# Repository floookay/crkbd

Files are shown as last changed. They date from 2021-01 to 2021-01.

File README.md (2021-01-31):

# Corne keyboard fork

The Corne keyboard is a split keyboard with 3x6 column staggered keys and 3 thumb keys,
based on [Helix](https://github.com/MakotoKurauchi/helix).
Crkbd stands for Corne Keyboard.

## Corne MX Low Profile

This fork altered the footprints of the Corne Classic to support Cherry MX Low Profile switches.  
For more information on how to build one see [here](./corne-mxlp/doc/buildguide_en.md)




### Compability

Despite the MX style stem of the switches these are not compatible with every MX style keycap. I included some more information in the build guide.

### RGB

The switches route the light of the RGB LEDs quite nicely imo: <https://imgur.com/7JVrjXo>



### PCB

I designed the footprint for the MXLP switch based on my measurements. The footprint file is included with the PCB. The switch has a tight fit.



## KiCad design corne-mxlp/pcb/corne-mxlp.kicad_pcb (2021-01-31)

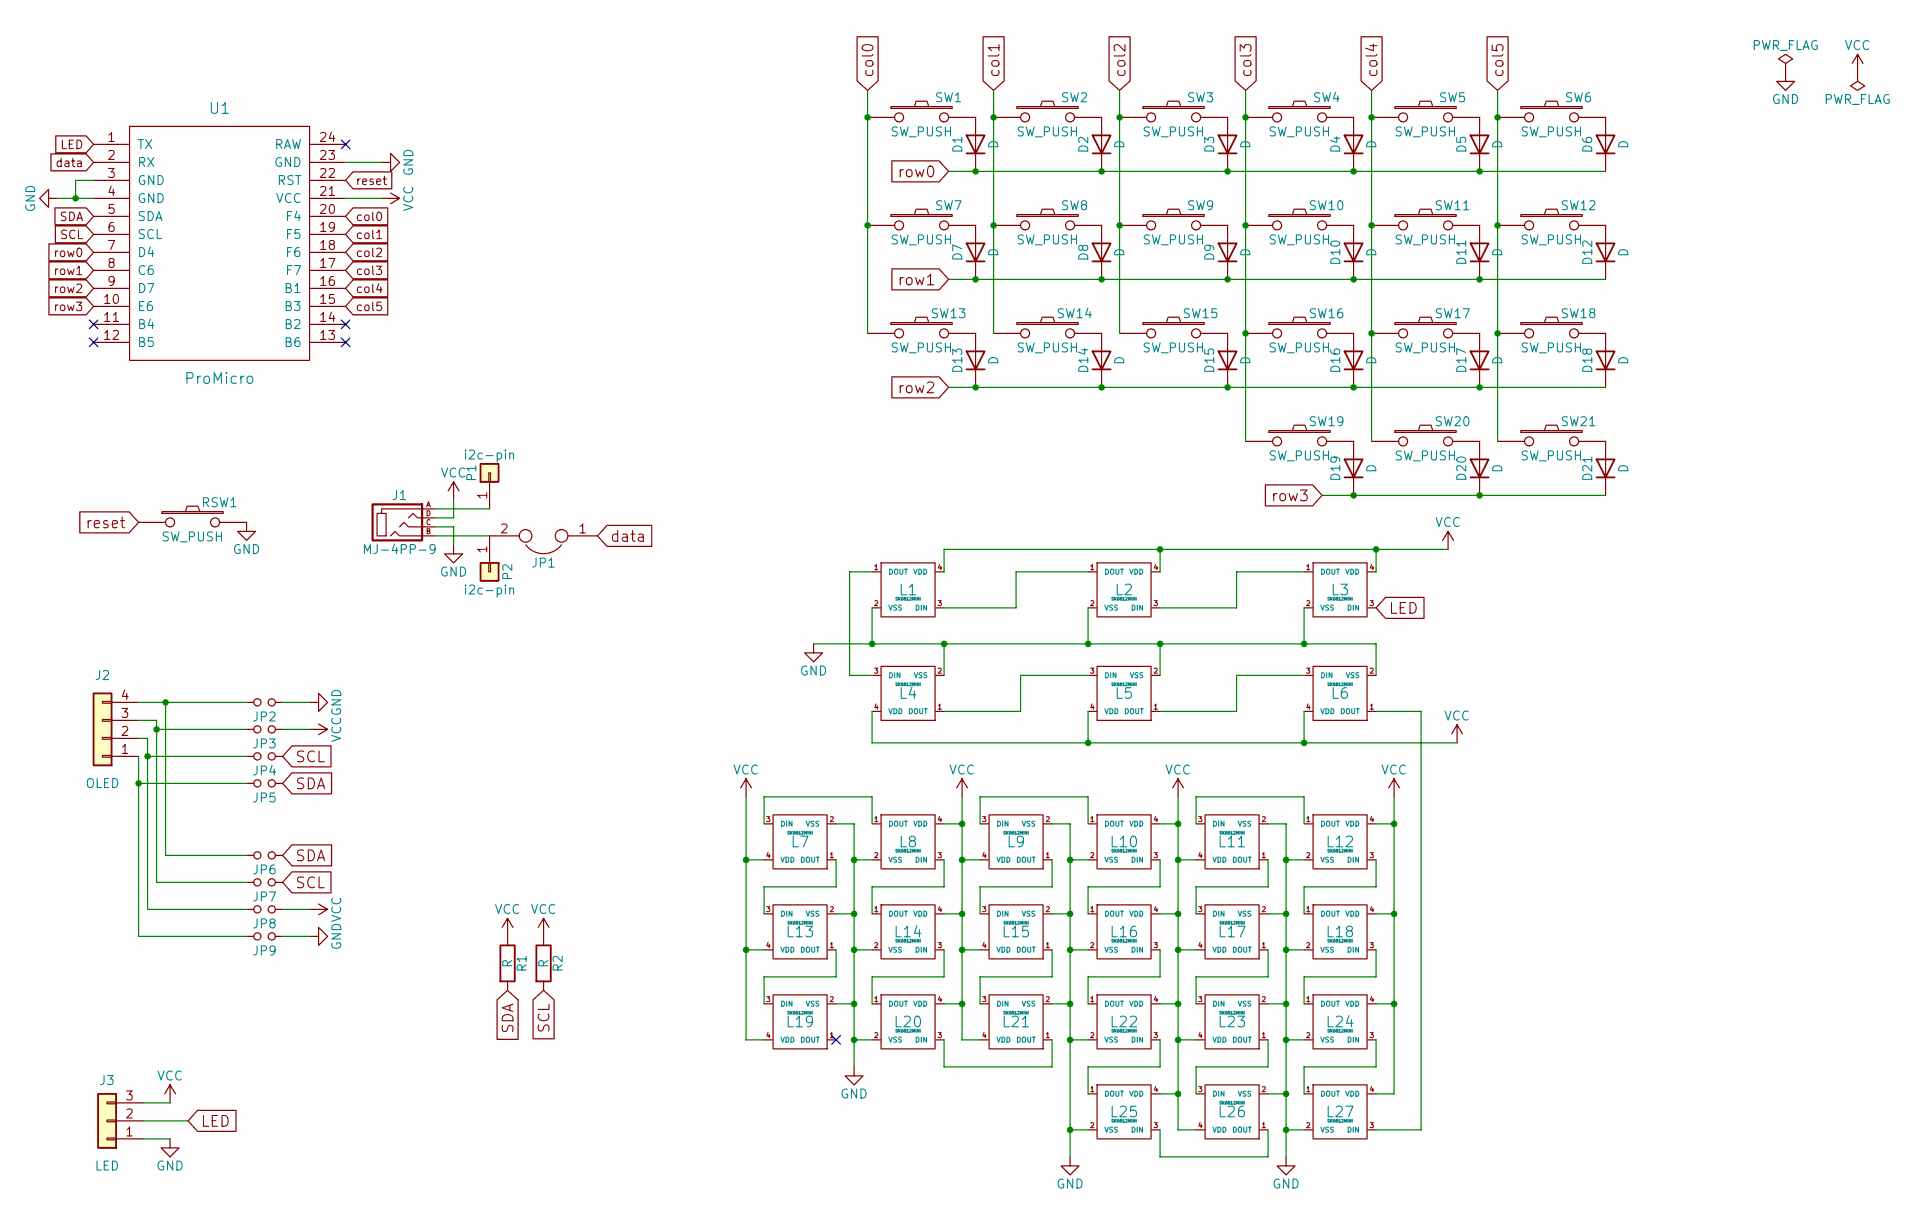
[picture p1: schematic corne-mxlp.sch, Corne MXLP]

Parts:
D1, D2, D3, D4, D5, D6, D7, D8, D9, D10, D11, D12, D13, D14, D15, D16, D17, D18, D19, D20, D21: D; D3_TH_SMD
J1: MJ-4PP-9
J2: OLED
J3: LED; StripLED_rev
JP1: JP
JP2, JP3, JP4, JP5, JP6, JP7, JP8, JP9: Jumper
L1, L2, L3, L4, L5, L6: SK6812MINI; SK6812MINI_underglow_rev
L7, L8, L9, L10, L11, L12, L13, L14, L15, L16, L17, L18, L19, L20, L21, L22, L23, L24, L25, L26, L27: SK6812MINI; SK6812MINI_rev
P1, P2: i2c-pin; 1pin_conn
R1, R2: R
RSW1: SW_PUSH; ResetSW
SW1, SW2, SW3, SW4, SW5, SW6, SW7, SW8, SW9, SW10, SW11, SW12, SW13, SW14, SW15, SW16, SW17, SW18, SW19, SW20, SW21: SW_PUSH; MXLP
U1: ProMicro; ProMicro_v2

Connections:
GND: J1.C, J3.1, JP2.1, JP9.1, L1.2 (VSS), L2.2 (VSS), L3.2 (VSS), L4.2 (VSS), L5.2 (VSS), L6.2 (VSS), L7.2 (VSS), L8.2 (VSS), L9.2 (VSS), L10.2 (VSS), L11.2 (VSS), L12.2 (VSS), L13.2 (VSS), L14.2 (VSS), L15.2 (VSS), L16.2 (VSS), L17.2 (VSS), L18.2 (VSS), L19.2 (VSS), L20.2 (VSS), L21.2 (VSS), L22.2 (VSS), L23.2 (VSS), L24.2 (VSS), L25.2 (VSS), L26.2 (VSS), L27.2 (VSS), RSW1.2, U1.3 (GND), U1.4 (GND), U1.23 (GND)
LED: J3.2, L3.3 (DIN), U1.1 (TX)
unnamed: D1.2 (A), SW1.2
unnamed: D2.2 (A), SW2.2
unnamed: D3.2 (A), SW3.2
unnamed: D4.2 (A), SW4.2
unnamed: D5.2 (A), SW5.2
unnamed: D6.2 (A), SW6.2
unnamed: D7.2 (A), SW7.2
unnamed: D8.2 (A), SW8.2
unnamed: D9.2 (A), SW9.2
unnamed: D10.2 (A), SW10.2
unnamed: D11.2 (A), SW11.2
unnamed: D12.2 (A), SW12.2
unnamed: D13.2 (A), SW13.2
unnamed: D14.2 (A), SW14.2
unnamed: D15.2 (A), SW15.2
unnamed: D16.2 (A), SW16.2
unnamed: D17.2 (A), SW17.2
unnamed: D18.2 (A), SW18.2
unnamed: D19.2 (A), SW19.2
unnamed: D20.2 (A), SW20.2
unnamed: D21.2 (A), SW21.2
unnamed: J1.A, P1.1
unnamed: J1.B, JP1.2, P2.1
unnamed: J2.1, JP5.2, JP9.2
unnamed: J2.2, JP4.2, JP8.2
unnamed: J2.3, JP3.2, JP7.2
unnamed: J2.4, JP2.2, JP6.2
unnamed: L1.1 (DOUT), L4.3 (DIN)
unnamed: L1.3 (DIN), L2.1 (DOUT)
unnamed: L2.3 (DIN), L3.1 (DOUT)
unnamed: L4.1 (DOUT), L5.3 (DIN)
unnamed: L5.1 (DOUT), L6.3 (DIN)
unnamed: L7.3 (DIN), L8.1 (DOUT)
unnamed: L9.3 (DIN), L10.1 (DOUT)
unnamed: L10.3 (DIN), L16.1 (DOUT)
unnamed: L11.1 (DOUT), L17.3 (DIN)
unnamed: L11.3 (DIN), L12.1 (DOUT)
unnamed: L12.3 (DIN), L18.1 (DOUT)
unnamed: L13.1 (DOUT), L19.3 (DIN)
unnamed: L7.1 (DOUT), L13.3 (DIN)
unnamed: L8.3 (DIN), L14.1 (DOUT)
unnamed: L14.3 (DIN), L20.1 (DOUT)
unnamed: L15.1 (DOUT), L21.3 (DIN)
unnamed: L9.1 (DOUT), L15.3 (DIN)
unnamed: L16.3 (DIN), L22.1 (DOUT)
unnamed: L17.1 (DOUT), L23.3 (DIN)
unnamed: L18.3 (DIN), L24.1 (DOUT)
unnamed: L20.3 (DIN), L21.1 (DOUT)
unnamed: L22.3 (DIN), L25.1 (DOUT)
unnamed: L23.1 (DOUT), L26.3 (DIN)
unnamed: L24.3 (DIN), L27.1 (DOUT)
unnamed: L25.3 (DIN), L26.1 (DOUT)
unnamed: L6.1 (DOUT), L27.3 (DIN)
SCL: JP4.1, JP7.1, R2.2, U1.6 (SCL)
SDA: JP5.1, JP6.1, R1.2, U1.5 (SDA)
VCC: J1.D, J3.3, JP3.1, JP8.1, L1.4 (VDD), L2.4 (VDD), L3.4 (VDD), L4.4 (VDD), L5.4 (VDD), L6.4 (VDD), L7.4 (VDD), L8.4 (VDD), L9.4 (VDD), L10.4 (VDD), L11.4 (VDD), L12.4 (VDD), L13.4 (VDD), L14.4 (VDD), L15.4 (VDD), L16.4 (VDD), L17.4 (VDD), L18.4 (VDD), L19.4 (VDD), L20.4 (VDD), L21.4 (VDD), L22.4 (VDD), L23.4 (VDD), L24.4 (VDD), L25.4 (VDD), L26.4 (VDD), L27.4 (VDD), R1.1, R2.1, U1.21 (VCC)
col0: SW1.1, SW7.1, SW13.1, U1.20 (F4)
col1: SW2.1, SW8.1, SW14.1, U1.19 (F5)
col2: SW3.1, SW9.1, SW15.1, U1.18 (F6)
col3: SW4.1, SW10.1, SW16.1, SW19.1, U1.17 (F7)
col4: SW5.1, SW11.1, SW17.1, SW20.1, U1.16 (B1)
col5: SW6.1, SW12.1, SW18.1, SW21.1, U1.15 (B3)
data: JP1.1, U1.2 (RX)
reset: RSW1.1, U1.22 (RST)
row0: D1.1 (K), D2.1 (K), D3.1 (K), D4.1 (K), D5.1 (K), D6.1 (K), U1.7 (D4)
row1: D7.1 (K), D8.1 (K), D9.1 (K), D10.1 (K), D11.1 (K), D12.1 (K), U1.8 (C6)
row2: D13.1 (K), D14.1 (K), D15.1 (K), D16.1 (K), D17.1 (K), D18.1 (K), U1.9 (D7)
row3: D19.1 (K), D20.1 (K), D21.1 (K), U1.10 (E6)

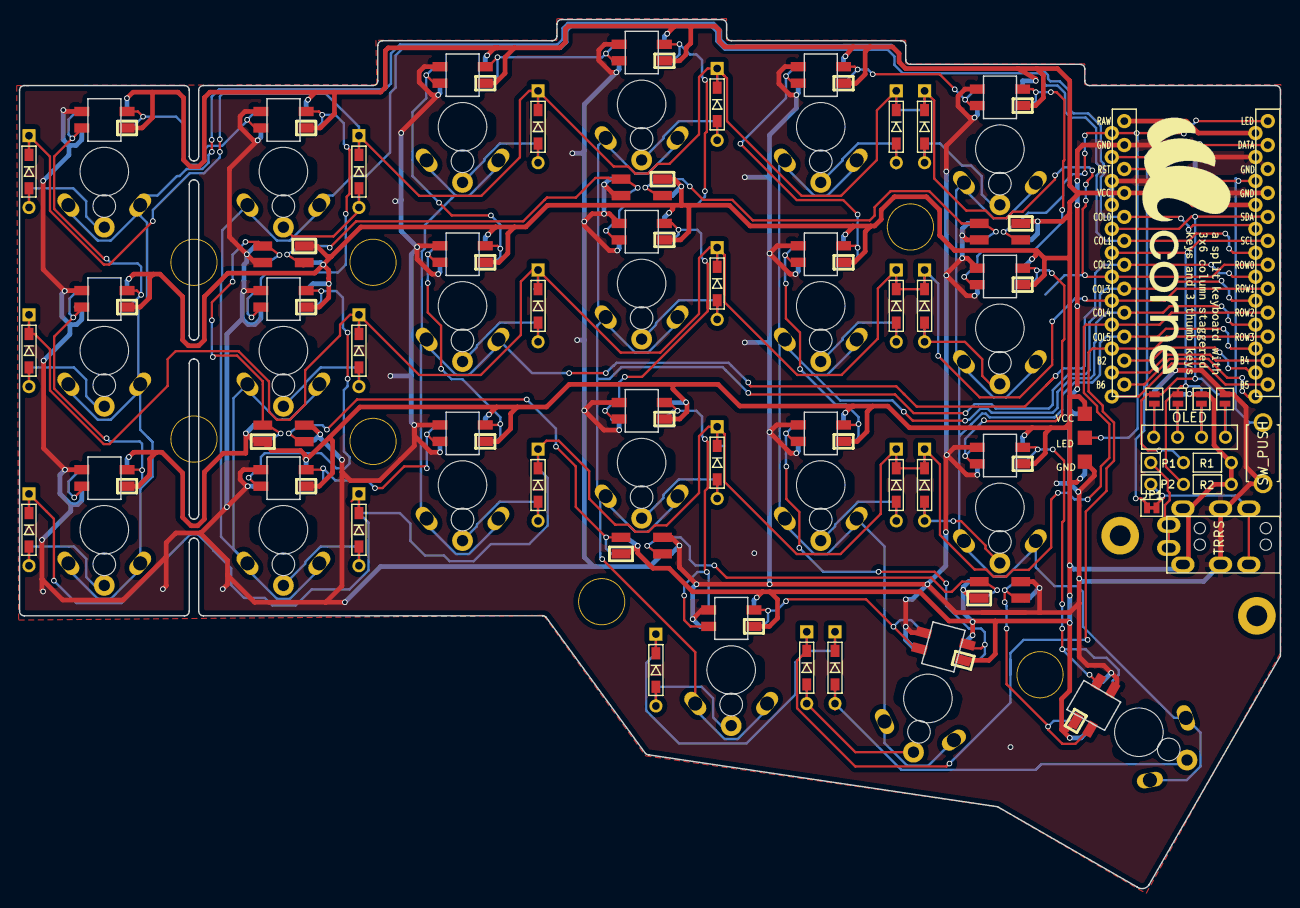
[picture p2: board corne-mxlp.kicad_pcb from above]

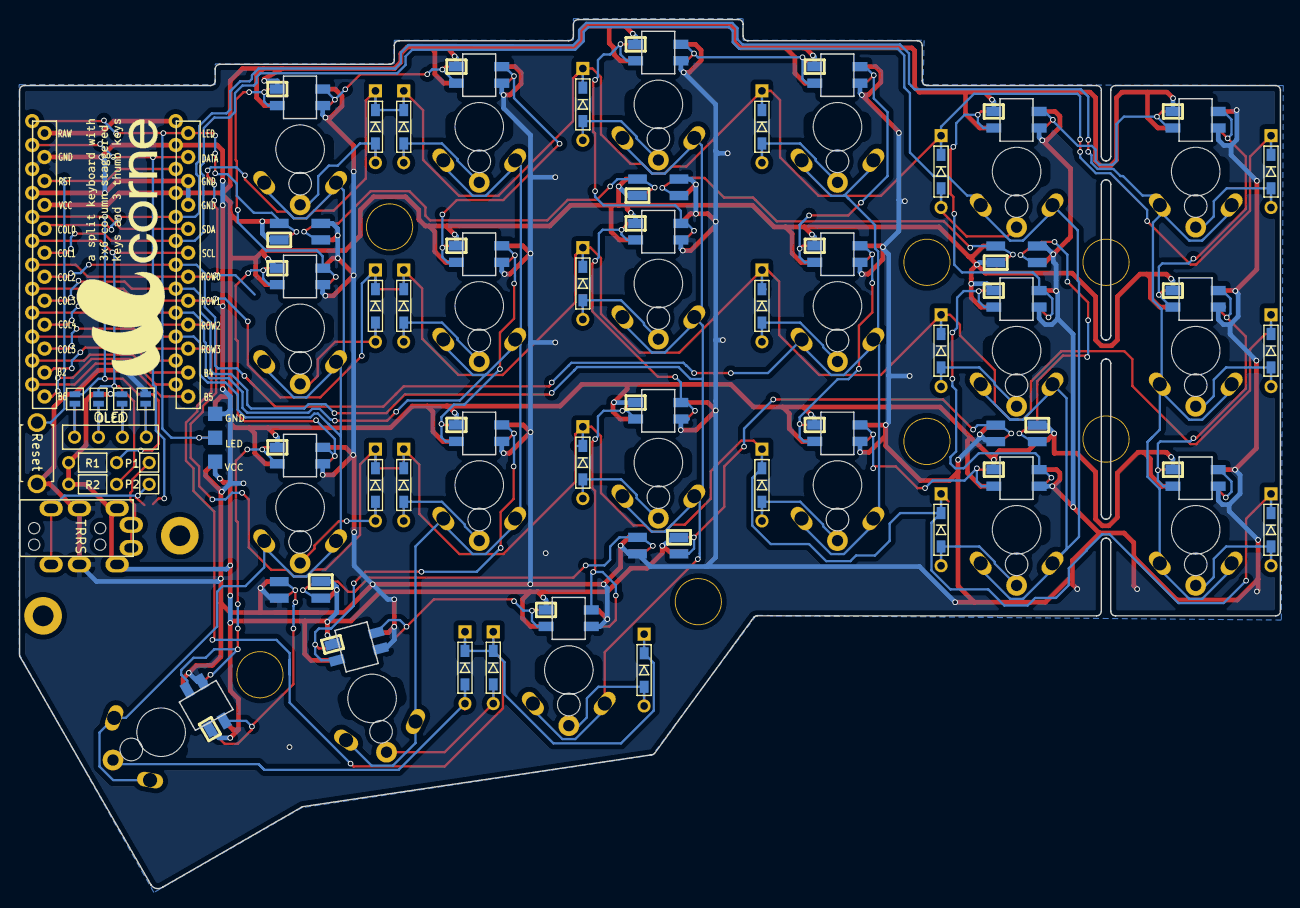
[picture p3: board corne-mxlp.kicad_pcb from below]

Board: 2 copper layers, 133.8 x 92.2 mm, 87 parts (4 on the bottom side), 70 nets.

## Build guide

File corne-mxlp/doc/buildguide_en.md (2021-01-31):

# Build Guide

## Parts
### Required
| Item | Count | Remark |
|:-|:-|:-|
| PCB | 2 | |
| Backplate + OLED Cover | 2 sets | no switch plate! |
| ProMicro | 2 | |
| TRRS Jack | 2 | |
| TRS(3 pole) cable | 1 | TRRS(4 pole) cable works too. |
| Tact switch | 2 | |
| Diode | 42 | |
| Key Switch | 42 | only Cherry MX Low Profile switches are supported |
| Key Cap | 42 | 1u x 40, 1.5u x 2 I'd recommend DSA or XDA |
| Hex brass standoff M2.5 5mm | 10 | doesn't have to be brass, but should be solid metal (no plastic!), 4mm should work too |
| Spacer M2 8mm or 10mm | 4 | |
| Screw M2 5mm | 8 | |
| Screw M2.5 5mm | 10 | |
| Rubber foot | 10 | |

### Optional
| Item | Count | Remark |
|:-|:-|:-|
| OLED Module + header  | 1 or 2 | |
| SK6812MINI | 54 | Front side x 42, back side x 12 |



## Notes

The building process is mostly the same to the original Corne. The main difference is the first step.

Although Cherry MX Low Profile switches do have the MX stem, not every keycap is supported. In fact, if you want to use this switch with a plate only low profile keycaps will work because every normal keycap will collide with the plate.  
I tested a bunch of different keycaps and found these to be working: DSA, XDA, SP SA, Maxkey SA, PBT MT3 if you grind off some parts of the switch  
GMK keycaps don't work. Small keys like the ones in row 3 will collide immediatelly with the switch so you can't even put them on all the way.  
If you want to know some more in thorough details about compability, I wrote a post [here](https://geekhack.org/index.php?topic=108218.0). 

## Hex Standoffs

**It's important that you do this step in the beginning because you could harm components if you do it at a later time.**

Mark the front side of each PCB so you don't mix them accidentially.  
Grab the standoffs and a hammer. Turn the PCBs on the backside and align a standoff with a mounting hole. Slightly hammer the standoff in until the other side of the standoff is flush with the PCB. Repeat the step for the other 9 standoffs.


&uarr; This picture was taken at a later time



## Soldering

PCB is reversible; use one for the left hand side and the other for the right.

### Diodes

Diodes will have to be mounted on the backside. Otherwise they'll probably collide with the keycap.  
You can use either, surface mount or through hole diodes.
If you're going to use through hole diodes, cut off the ends of the diodes so they're flush with the PCB.

### LEDs (Optional)

Implement LEDs under keyswitches (No. 7 through 27) upward facing, and others (No. 1 through 6) on the back side(under-glow), as indicated in the picture.



For No.7 to 27 LEDs, __Install LEDs from the back side__ as shown below.
Note the '**o**' silkscreen marking and use them as a guide to implement LEDs in the direction. On some versions  of the PCB (e.g. Corne-cherry v2), the '**o**' silkscreen marking has been replaced by a white square around one of the pads, but the principle is still the same.



The LED has one pad that is shaped like a square. That square should connect to the pad that has the '**o**' silkscreen marking:



There are many different techniques on how to solder the LEDs, but [this video](https://twitter.com/foostan/status/1005656803818889216) might give you an idea on how to do it.

For No. 1 to 6 LEDs, solder the pattern on the side of the device (highlighted in pink on the picture) and the PCB pattern(blue on the picture). Apply flux and take small amount of solder with a soldering iron and press it on the edge of the patterns.



LEDs are connected in the order of the number on the picture above. If it turns on only halfway, it is likely that first LED that doesn't turn on or the last LED that turns on is not implemented correctly.

__Note__ that the default Crkbd firmware has __LEDs turned off__, so you'll have to turn them on before you can test (see the firmware section for instructions how).

### Jumpers for OLED modules (optional)
To use OLED modules, short circuit the jumper patterns.
__Only short circuit the front side__



### TRRS socket, reset switch, OLED header sockets.

Install TRRS sockets and reset switches as in the picture.
For OLEDs, also implement pin sockets.



### ProMicro

Before you start, flash the Crkbd firmware to the ProMicros to make sure they are alright.

The pins of this forks PCB havn't changed so you can use the same firmware you would use on a classic Corne.

The ProMicro is then installed __in the set of wholes that has a white frame on the frontside of the PCB__. Make sure you solder it in the right set of holes, as desoldering the ProMicro is hard. Implement pin headers in the white frame, then install ProMicro with its __backside up__.



The picture is the right hand side, but it's the same for the left hand side - pins into the through holes in the white frame as seen from the frontside, placing the ProMicro with its backside up.

### OLED Module
Implement pin header onto the OLED modules, then insert them into the pin sockets.



Adjust the height of the spacer accordingly to the height of pin header.
Most common pin header/socket and 10mm spacers are used in the picture.

### Use socket to Mount ProMicro

With using sockets for mounting ProMicro, you can replace it easily when it breaks. Two methods are introduced here.

#### Using Spring Loaded Header

Refer to [Helix Buildguide](https://github.com/MakotoKurauchi/helix/blob/master/Doc/buildguide_en.md#pro-micro)

ProMicro kit with spring loaded headers is available at Yusha-Kobo

https://yushakobo.jp/shop/promicro-spring-pinheader/

Using OLEDs available at Yusha-Kobo which come with low profile header, together with and 8mm spacers, you can build them think and gap-less.



#### Using Pin Sockets
Low profile pin sockets are available from Akizuki Denshi etc. Requires some work.

http://akizukidenshi.com/catalog/g/gC-03138/

Install a couple of 12x1 pin sockets on a breadboard.



Using male 12x1 pin headers, fixate ProMicro onto the pin sockets.



Remove plastic pin holders, solder the pins to ProMicro, and then cut extra pins.



#### Comparison

Spring loaded headers can make the height lower.



Comparing pin-headers in the picture. Headers come with OLED available at Yusha-Kobo are lower.



### Testing
It is recommended to test the ProMicro and OLED modules before installing keyswitches because rework would be difficult after that.

First, build QMK Firmware for built for Crkbd and install on ProMicro (if you haven't already done so).



Using the default keymap, OLED will show information on the keyswitches being pressed. Check the connections by short-circuiting keyswitch soldering pads with tweezers or a bit of soldering wire. Check all of them.

If you have OLED displays, you can verify that all keys are responding by looking at the log information showed there. It will say which row and column was pressed, e.g. `1x5` or `0x2`. Using the tweezers or wire, connect each buttons soldering pads and make sure the display changes. If something isn't working, take note of the which row x column it is that isn't working, as it can help when troubleshooting.

If you have mounted LEDs, also make sure all of them are turned on. As note before, the default firmware has LEDs __turned off__, so you have to turn them on in the firmware before you test.



### Bottom Plate
Attach bottom plate to the standoffs on the PCB.
Then attach five rubber feet.




### Keycaps
Lastly install keycaps.




## Firmware
Setup firmware build environment following the instructions here:
https://docs.qmk.fm/#/newbs_getting_started

Then build firmware for Crkbd with this command:

```
make crkbd:default
```

To flash the firmware image you have just built, execute this:

```
make crkbd:default:avrdude
```

You will see `.` after a message like below.
While you see `.` is being printed on the screen, push the reset switch __twice__.

```
(snip)

Checking file size of crkbd_rev1_default.hex                                                        [OK]
 * File size is fine - 27328/28672
Copying crkbd_rev1_default.hex to qmk_firmware folder                                               [OK]
Detecting USB port, reset your controller now........
```

Flash the firmware to the other side as well.

### Turning LEDS on
To turn the LEDs on, you have to edit the `rules.mk` file. If you use the default layout, it can be found here `keyboards/crkbd/keymaps/default/rules.mk`. Add the following line to the top of the file:
```
RGBLIGHT_ENABLE = yes
```

Compile and flash to both sides and all LEDs should turn on and __glow red__ if you have soldered everything correctly. If you run the default firmware and the LEDs turn a differrent color, the data to the LEDs is probably corrupted somewhere along the way. Check the LED before the first one turning a different color using the troubleshooting guide below.

## Troubleshooting
Here are some tips and tricks on how to troubleshot a board that is not working.

### No LEDs turn on
There are a number of things that might be wrong. First of all, make sure you have __turned on LED lighting in the firmware__. If that is the case, then chances are there might be a problem with the first LED. Try the suggestions in the next section.

### Some LEDs not turning on
If some LEDs aren't turning on, check the first LED not turning on __or__ the one before it.

LED numbering on the PCB

Here are some things to try out:
- Make sure the LED is soldered correctly. Check the pads to see if it looks like they have a proper connection.
- Check the LED orientation. Use the pictures above the see the correct orientation. Since the first LED is soldered with its back against the PCB, you might have to determinewhat the orientation should look like from the front using LEDs 7-27 (just double check that they are oriented correctly first).
- If both of the above looks good, chances are the LED was damaged during soldering. Either replace it directly or use the diod mode of a multimeter to test the connectivity. One way to do this is by simply comparing to some of the other LEDs you have soldered. Choose two of the LED's pads (out of the four available) and compare the reading to that of some of the other LEDs (taking care to measure the same pads with the same needles of your multimeter). Work your way through all combinations of pads and needles. If the differ, you either have a broken LED or bad connectivity. Or simply desolder the LED directly, might be quicker. :)

### A full row/column of keys not working
If a full row or column of keys is not working, then the culprit is most likely the connection between the PCB and the ProMicro. Check your soldering and make sure there's a proper connection and that you have soldered the ProMicro in the right set of holes. If soldering looks okay, then your ProMicro might be damaged. You can exclude the possibility of problems with the PCB, paths and diodes by short circuiting the pins on the ProMicro directly using a bit of wire. Connecting one row pin with one column pin should result in the corresponding key. Some PCBs have silkscreen print indicating which pin is which row or column, to make this process easier.

### Random key(s) not working
If it is not a full row or column of keys that are not working, the issue is most likely that there's no connection between the key and the ProMicro. There are multiple places where the connection can get interupted:

- between keyswitch and PCB (if you have installed the switches)
- between keyswitch and hotswap socket (if you use them)
- between hotswap socket and PCB (again, if you use hotswap sockets)
- in the diodes between the key and the ProMicro
- in the paths inside the PCB

If you have installed the keyswitches already, then check the soldering on the keyswitch. if you use hotswap sockets, check that you didn't accidentally bend one of the legs of the switch when inserting into the socket and that the socket soldering is alright.

Next, visually inspect the PCB. If it looks scratched or damaged anywhere along the path from ProMicro to diode to keyswitch, the path might be interrupted. If you find a spot that looks damaged, you can use some wire to bypass the section that is damaged (e.g. connecting the ProMicro directly to the first pad of the diode). If this fixes the key, then you can either opt to keep the wire permanently, or you can try to repair the path. The path can be repaired by carefully scraping off the paint from a section of the path that is okay on either side of the damaged part (use a small flat head screwdriver intended for electronics). Then clean carefully with alcohol and solder a new connection. Youtube might have some guides on how to do this.

If the PCB looks okay, then the diode would be the next thing to check. Begin by checking the soldering. If it looks okay, then the diode itself might be damaged. If you have a multimeter, use it to check the diode. The reading should be the same as for diodes connected to keys that are working (when measuring, remember that diodes have polarity). You can also use tweezers or a bit of soldering wire to connect the soldering pads on each side of the diode if you don't have a multimeter. Pressing the key (or short circuiting the pads where the key would go) after connecting the pads should make a key press being registered. If this is the case, or if you used the multimeter and got a different reading from the diode, then check your soldering and replace the diode if necessary.
